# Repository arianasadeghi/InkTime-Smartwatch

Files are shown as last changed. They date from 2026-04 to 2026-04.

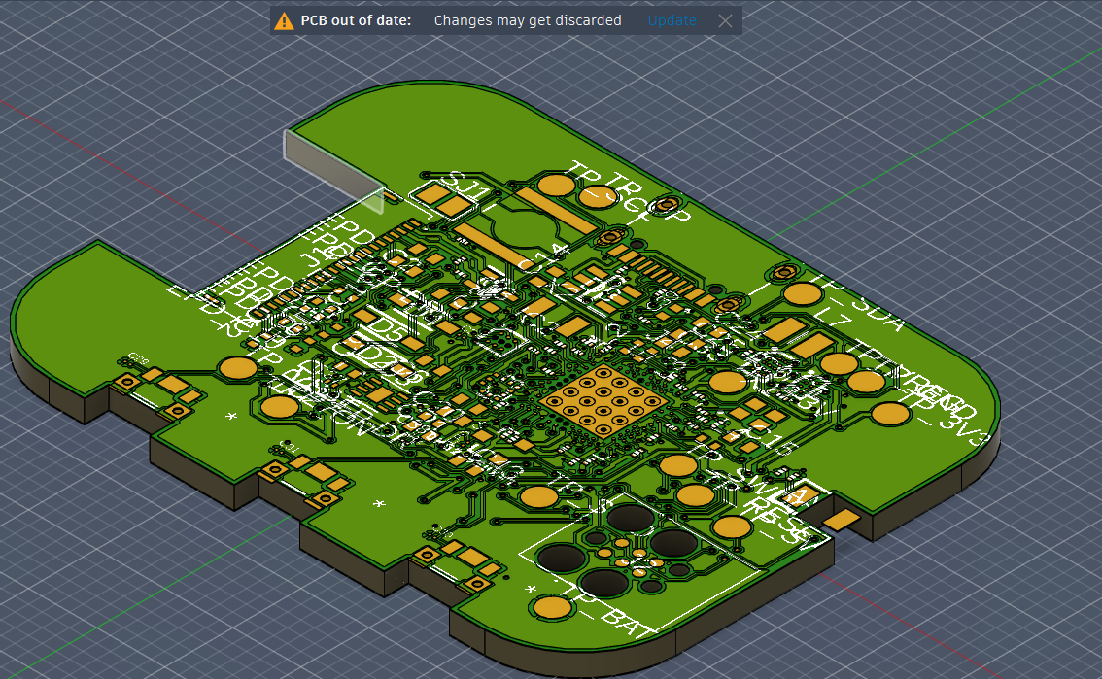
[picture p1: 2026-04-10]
IMAGES/3D1.png

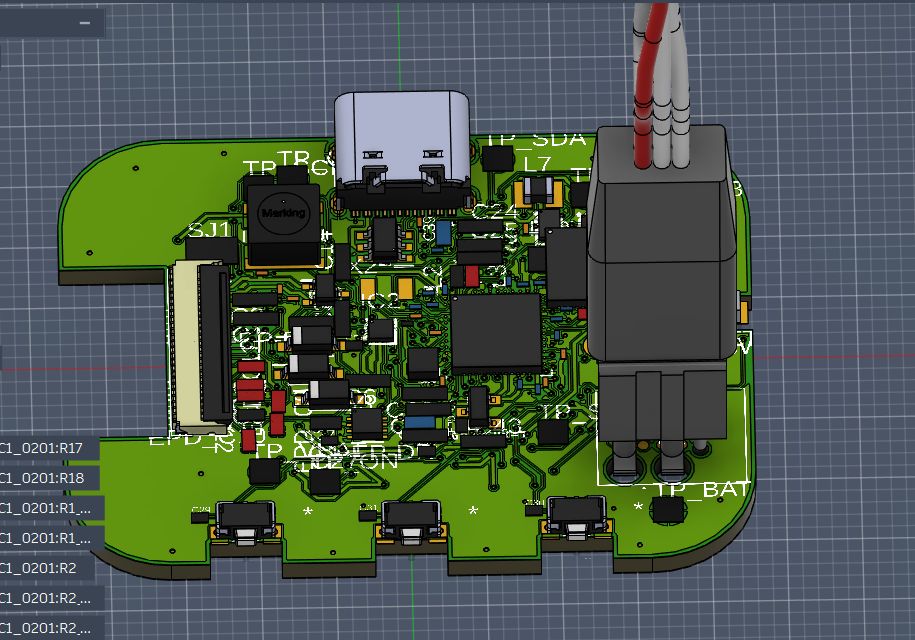
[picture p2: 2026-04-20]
IMAGES/PCB3D.png

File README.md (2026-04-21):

# InkTime - Open Source Smartwatch

InkTime este un proiect de smartwatch accesibil, open-source, conceput cu un accent puternic pe eficiența energetică și autonomia bateriei. Dispozitivul este construit în jurul ecosistemului nRF52840 (oferind conectivitate Bluetooth Low Energy) și folosește un ecran E-Ink pentru a asigura o vizibilitate excelentă în lumina soarelui cu un consum de energie aproape nul în stand-by.

Acest repository conține fișierele de design hardware pentru faza **EVT (Engineering Validation Test)**.

## 1. Diagrama Bloc a Sistemului

```mermaid
graph TD
    %% Power Management
    USB[Mufă USB-C / Pogo Pins] -->|5V| CHG[IC Încărcare BQ24040]
    CHG --> BATT[Acumulator LiPo 3.7V]
    BATT --> LDO[Regulator LDO 3.3V Ultra-Low Iq]
    
    %% Core
    LDO -.->|3.3V| MCU[SoC nRF52840]
    
    %% Interfaces & Peripherals
    MCU <-->|SPI| EINK[Display E-Ink 1.54]
    MCU <-->|I2C| IMU[Accelerometru BMA400]
    MCU <-->|I2C| HR[Senzor Puls MAX30102]
    MCU -->|GPIO| VIB[Motor Vibrații]
    MCU -->|GPIO| BTN[Butoane Navigare]
    
    %% Power lines
    LDO -.->|3.3V| EINK
    LDO -.->|3.3V| IMU
    LDO -.->|3.3V| HR
```

## 2. Bill Of Materials (BOM)

Tabelul de mai jos conține componentele principale folosite în designul plăcii. Lista completă (inclusiv rezistențe și condensatoare) se găsește în fișierul .csv din folderul Manufacturing.
| Componenta | Rol în sistem | JLC Part # | Link Datasheet |
| :--- | :--- | :--- | :--- |
| **nRF52840-QIAA** | Microcontroller principal (BLE, Cortex-M4F) | C206001 | [Datasheet nRF52840](https://infocenter.nordicsemi.com/pdf/nRF52840_PS_v1.7.pdf) |
    | **BQ24040DSQR** | IC Incarcare Acumulator LiPo (1A) | C43012 | [Datasheet BQ24040](https://www.ti.com/lit/ds/symlink/bq24040.pdf) |
| **TPS7A0533PDQNR** | LDO 3.3V (Consum Quiescent extrem de mic - 1µA) | C396492 | [Datasheet TPS7A05](https://www.ti.com/lit/ds/symlink/tps7a05.pdf) |
| **BMA400** | Accelerometru Ultra-Low Power (Pedometer) | C383215 | [Datasheet BMA400](https://www.bosch-sensortec.com/media/boschsensortec/downloads/datasheets/bst-bma400-ds000.pdf) |
| **MAX30102** | Senzor Optic Puls și SpO2 | C84666 | [Datasheet MAX30102](https://www.analog.com/media/en/technical-documentation/data-sheets/MAX30102.pdf) |
| **Ecran E-Ink 1.54 inch** | Display principal (SPI) | N/A (Modul) | [Datasheet Waveshare](https://www.waveshare.com/wiki/1.54inch_e-Paper_Module) |
## 3. Descrierea Functionalitatii Hardware

### Procesare si Conectivitate:
Inima ceasului InkTime este SoC-ul Nordic nRF52840. A fost ales datorita suportului nativ pentru Bluetooth 5.0 (BLE), esential pentru sincronizarea notificarilor cu telefonul mobil. Arhitectura ARM Cortex-M4F permite procesarea eficienta a algoritmilor de numarare a pasilor si calcul al ritmului cardiac.

### Managementul Consumului de Energie (Power Tree):
Fiind un dispozitiv wearable, constrângerile de baterie sunt critice.

Sistemul este alimentat de o baterie LiPo de mici dimensiuni (ex. 200mAh).

Încărcarea se face la 5V printr-un circuit BQ24040, reglat din rezistențe pentru a oferi un curent de încărcare mic și sigur (ex. 100mA).

Pentru a coborî tensiunea la 3.3V am folosit un LDO din seria TPS7A05, care are un curent de repaus (Iq) de doar 1µA, esențial pentru a nu drena bateria când ceasul este în Deep Sleep.

### Periferice și Interfețe:

Display-ul E-Ink: Comunică prin protocol SPI. Deși are un framerate mic, este perfect pentru un ceas deoarece consumă 0mA pentru a menține imaginea afișată.

Senzorii (IMU & HR): Comunicația se realizează pe o magistrală I2C partajată. BMA400 are un mod special de "step counter" hardware care poate trezi microcontroller-ul din sleep doar când utilizatorul face un pas, economisind masiv energia.

## 4. Alocarea Pinilor nRF52840

Microcontroller-ul nRF52840 permite maparea flexibilă a pinilor (orice funcție digitală pe orice pin), lucru care a facilitat o rutare curată (fără suprapuneri) pe PCB.
| Pin nRF52840 | Nume Net / Funcție | Justificare / Detalii |
| :--- | :--- | :--- |
| **P0.13 / P0.14 / P0.15** | `SPI_SCK`, `SPI_MOSI`, `SPI_MISO` | Magistrala SPI dedicată ecranului E-Ink. Pinii au fost aleși pe aceeași latură a chip-ului cu conectorul FPC al ecranului. |
| **P0.16** | `EINK_CS` (Chip Select) | Activare magistrală SPI pentru ecran. |
| **P0.17 / P0.18** | `EINK_DC`, `EINK_RST` | Pini de control adiționali (Data/Command și Reset) necesari controller-ului de E-Ink. |
| **P0.26 / P0.27** | `I2C_SDA`, `I2C_SCL` | Magistrala I2C pentru accelerometru (BMA400) și senzorul de puls (MAX30102). Conține rezistențe de pull-up de 4.7k. |
| **P1.02** | `IMU_INT` (Interrupt) | Pin setat ca Input. BMA400 trimite un semnal aici pentru a trezi SoC-ul când detectează mișcare. |
| **P1.06** | `MOTOR_PWM` | Pin configurat ca ieșire PWM, conectat la poarta unui tranzistor MOSFET N-Channel pentru a acționa motorul de vibrații (notificări haptice). |
| **P0.11 / P0.12** | `BTN_UP`, `BTN_DOWN` | Pini conectați la butoanele laterale, configurați cu Input Pull-Up intern. |
## 5. Design Log & Integrare Mecanică (EVT Phase)

### Construcția PCB-ului: 
Cablajul a fost realizat pe 2 straturi. Pentru a asigura performanța antenei, a fost respectată zona de keepout cerută în datasheet-ul antenei ceramice (sau PCB trace), neavând planuri de masă sub aceasta.

### Constrângeri Mecanice: 
Forma PCB-ului a fost dictată strict de fișierul .step al carcasei primite. Decupajele plăcii se aliniază perfect cu pinii de montare ai carcasei.

### Stack-up 3D: 
Modelul 3D final validează faptul că placa de bază, bateria (poziționată sub PCB) și display-ul E-Ink (deasupra PCB-ului) intră în carcasa de smartwatch fără coliziuni de componente.

## 5. Calcule Detaliate de Consum de Energie (Power Budget)

Pentru a estima durata de viata a bateriei, am analizat consumul principalelor componente din circuit (nRF52840, IMU, DC/DC converter) in doua scenarii principale: Mod Activ si Mod Sleep (Standby).

### 1. Parametrii Bateriei
* Tip baterie: Li-Po
* Tensiune nominala: 3.7V
* Capacitate: 500 mAh

### 2. Consum in Mod Activ (Transmisie BLE + Achizitie Date IMU)
Cand dispozitivul este treaz, citeste date de la senzori si transmite pachete prin Bluetooth.
* nRF52840 (CPU + TX/RX la 0dBm): ~14.0 mA
* Senzor IMU (Mod Activ): ~1.0 mA
* Pierderi DC/DC Converter (Eficienta 90%): ~1.5 mA
* Total Consum Activ: ~16.5 mA

### 3. Consum in Mod Sleep (Standby / System OFF)
Cand dispozitivul nu este folosit, microcontrolerul intra in deep sleep, iar senzorii sunt trecuti in power-down.
* nRF52840 (System OFF, RAM retention): ~1.5 uA (0.0015 mA)
* Senzor IMU (Mod Power-Down): ~5.0 uA (0.005 mA)
* Quiescent Current DC/DC + LDO: ~10.0 uA (0.01 mA)
* Total Consum Sleep: ~16.5 uA (0.0165 mA)

### 4. Estimarea Duratei de Viata a Bateriei (Battery Life)

Scenariul A: Utilizare Continua (100% Mod Activ)
Daca dispozitivul ar transmite date non-stop:
* 500 mAh / 16.5 mA = 30.3 ore de functionare continua.

Scenariul B: Dispozitiv lasat pe birou (100% Mod Sleep)
Daca dispozitivul este pur si simplu lasat in stand-by:
* 500 mAh / 0.0165 mA = 30,303 ore = Aproximativ 3.4 ani.

Scenariul C: Utilizare Realista (Mix: 5% Activ, 95% Sleep)
Presupunand ca dispozitivul se trezeste periodic pentru a trimite date:
* Consum mediu = (16.5 mA * 0.05) + (0.0165 mA * 0.95) = 0.825 mA + 0.015 mA = 0.84 mA

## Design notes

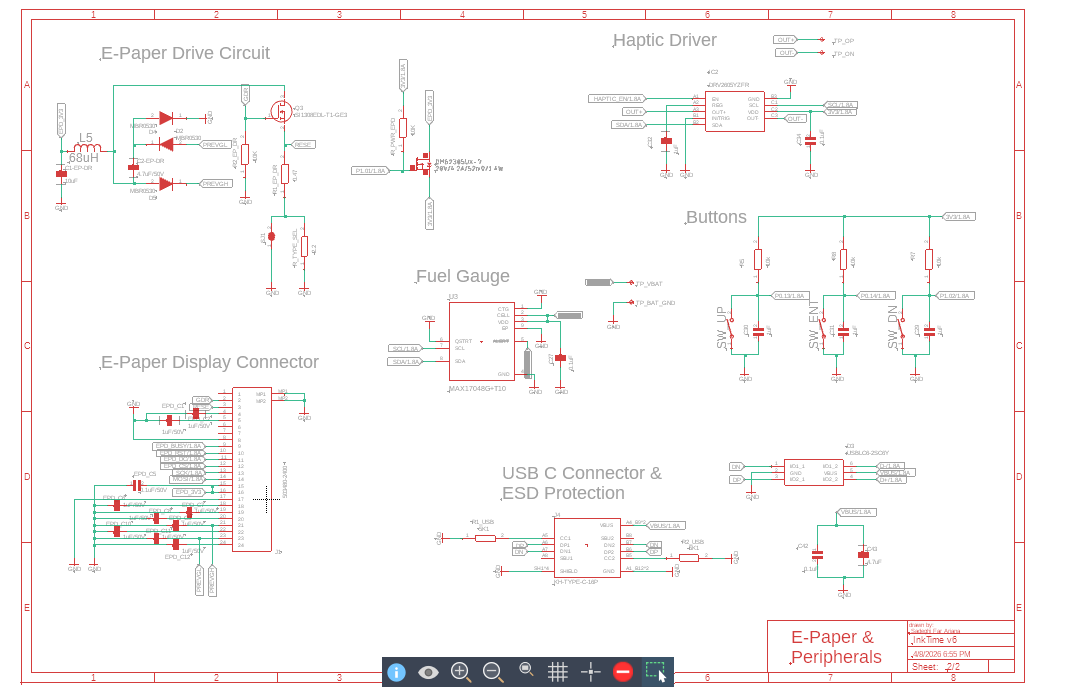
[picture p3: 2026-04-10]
IMAGES/Schematic2.png

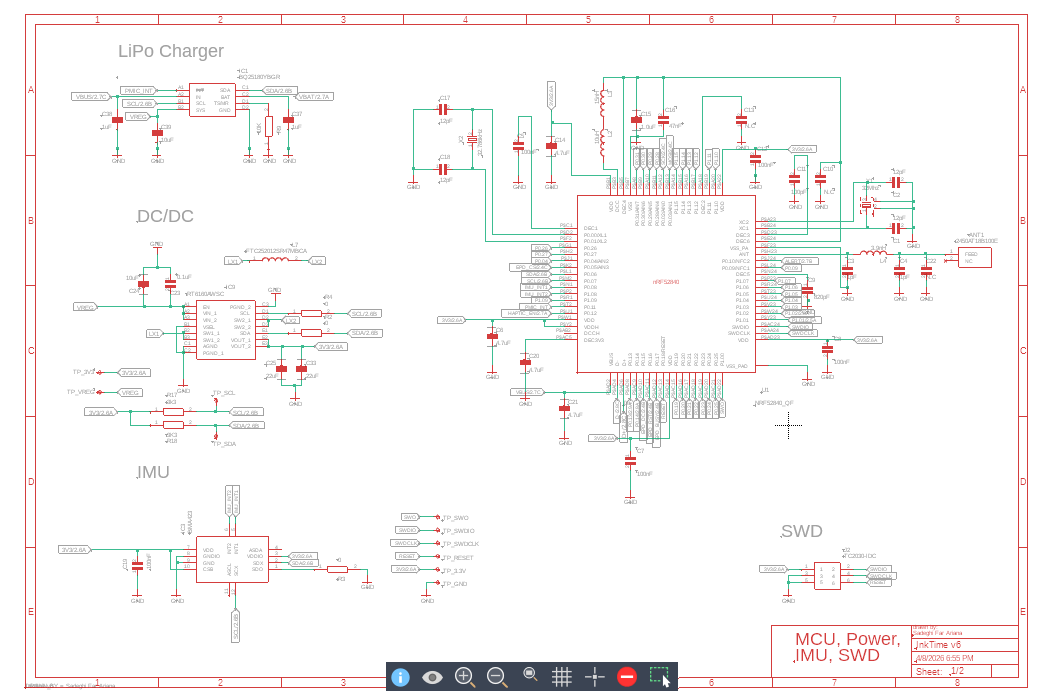
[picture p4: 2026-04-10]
IMAGES/Schematic1.png

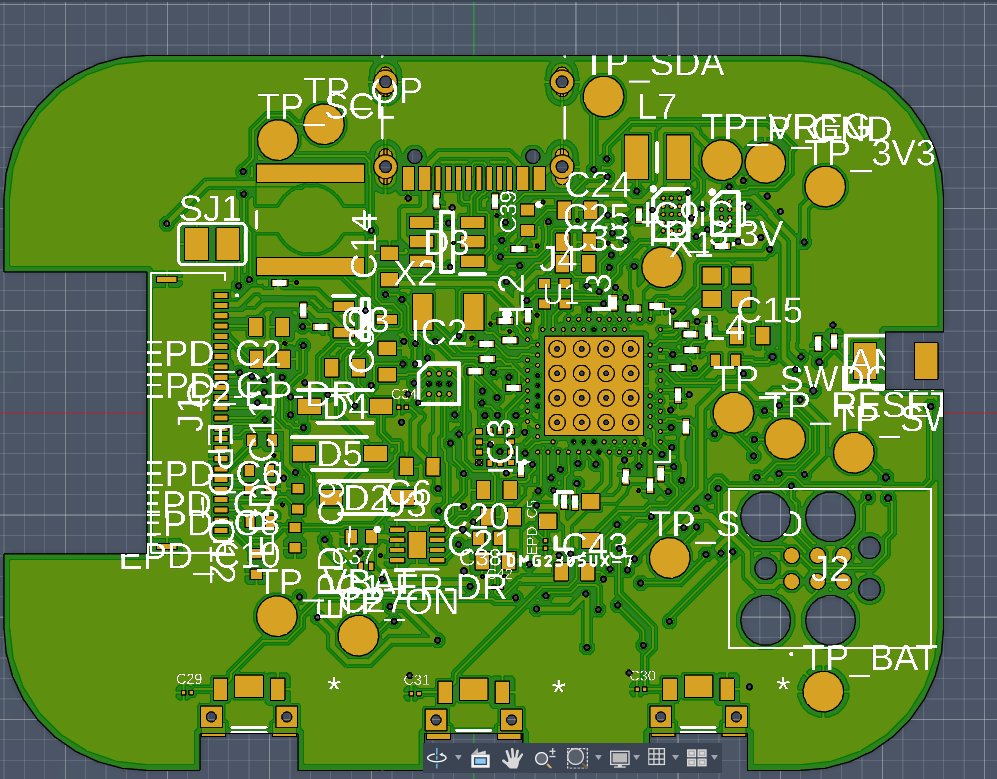
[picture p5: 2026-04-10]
IMAGES/3D2.png

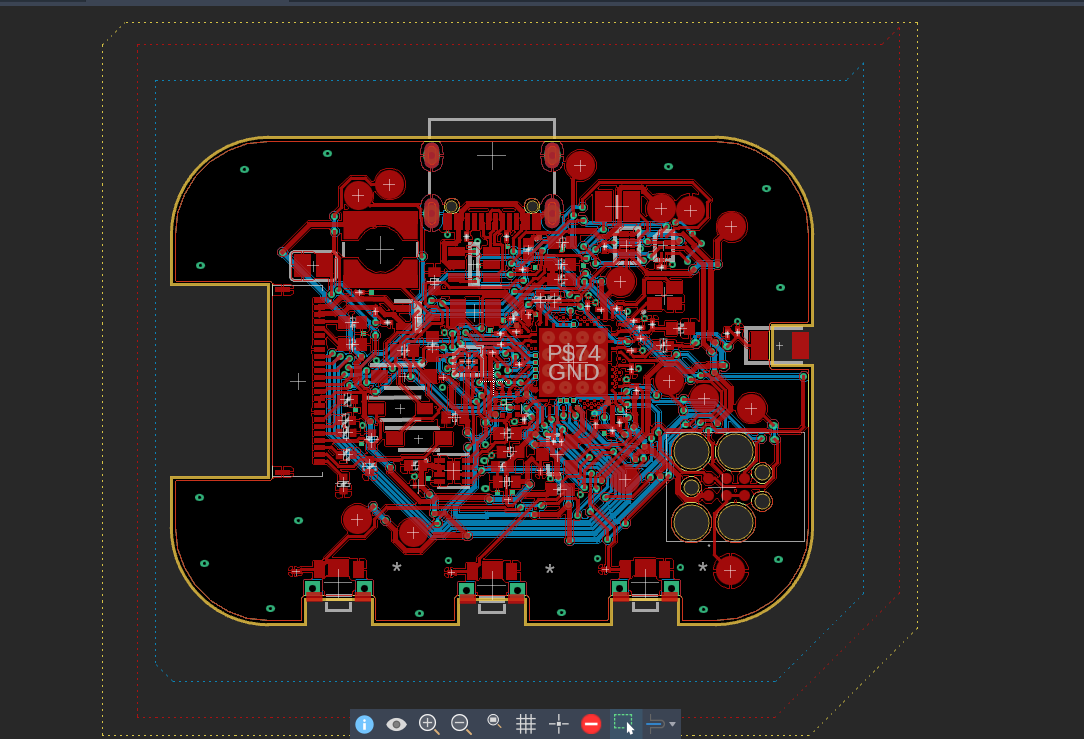
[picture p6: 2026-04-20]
IMAGES/PCB.png

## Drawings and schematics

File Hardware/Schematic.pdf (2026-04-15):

# LiPo Charger

1 2 C18

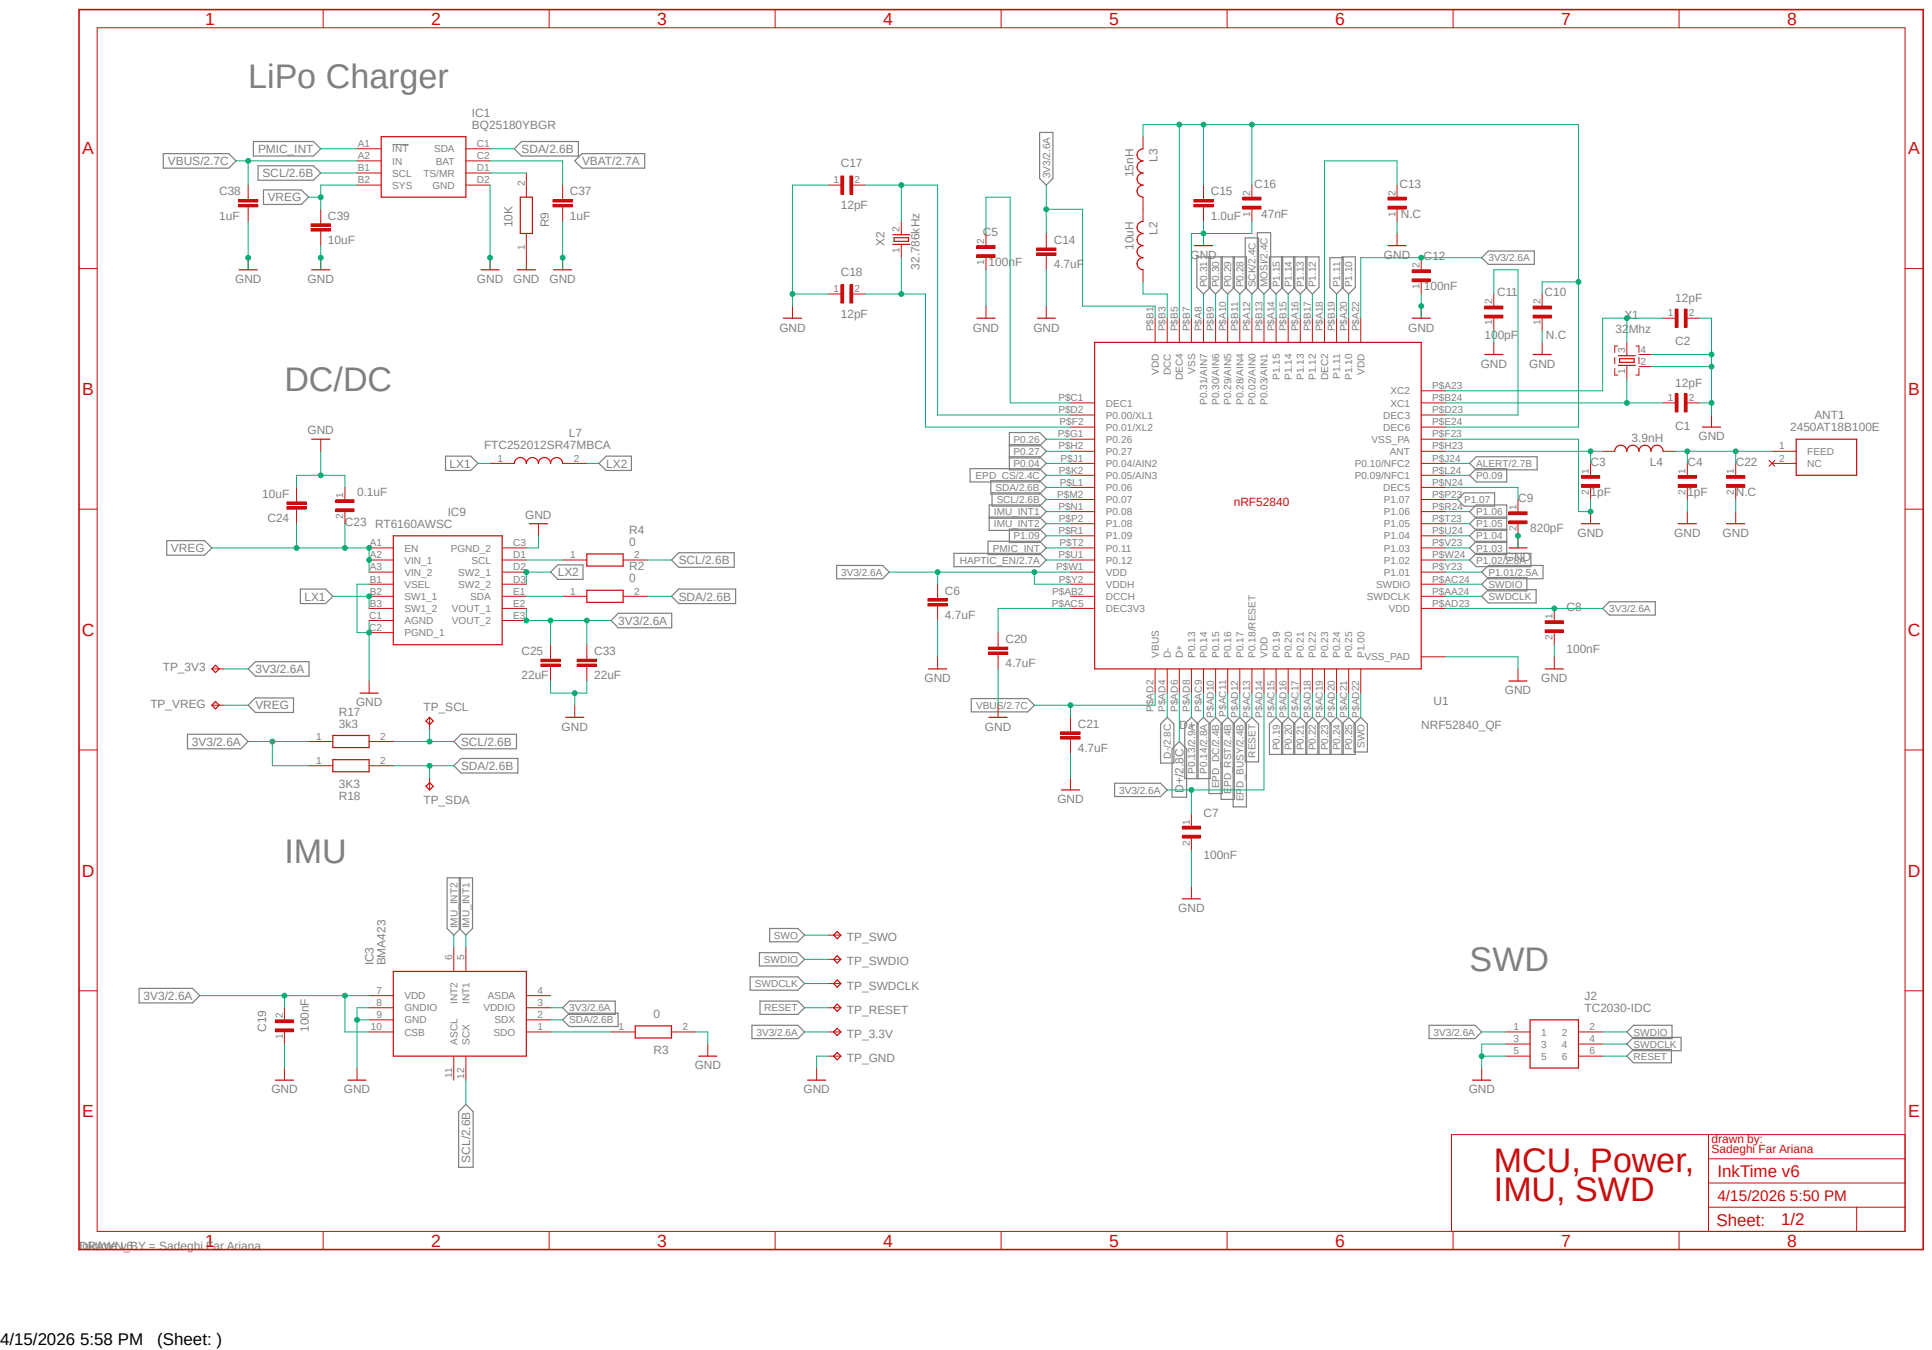
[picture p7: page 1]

6 VDD 7 GNDIO 8 GND 9 CSB 10 ASCL 11 SCX 12

IMU, SWD | drawn by: Sadeghi Far Ariana MCU, Power,

Sheet: 1/2

DRAWN_BY = Sadeghi Far Ariana Inktime v6

# Haptic Driver E-Paper Drive Circuit

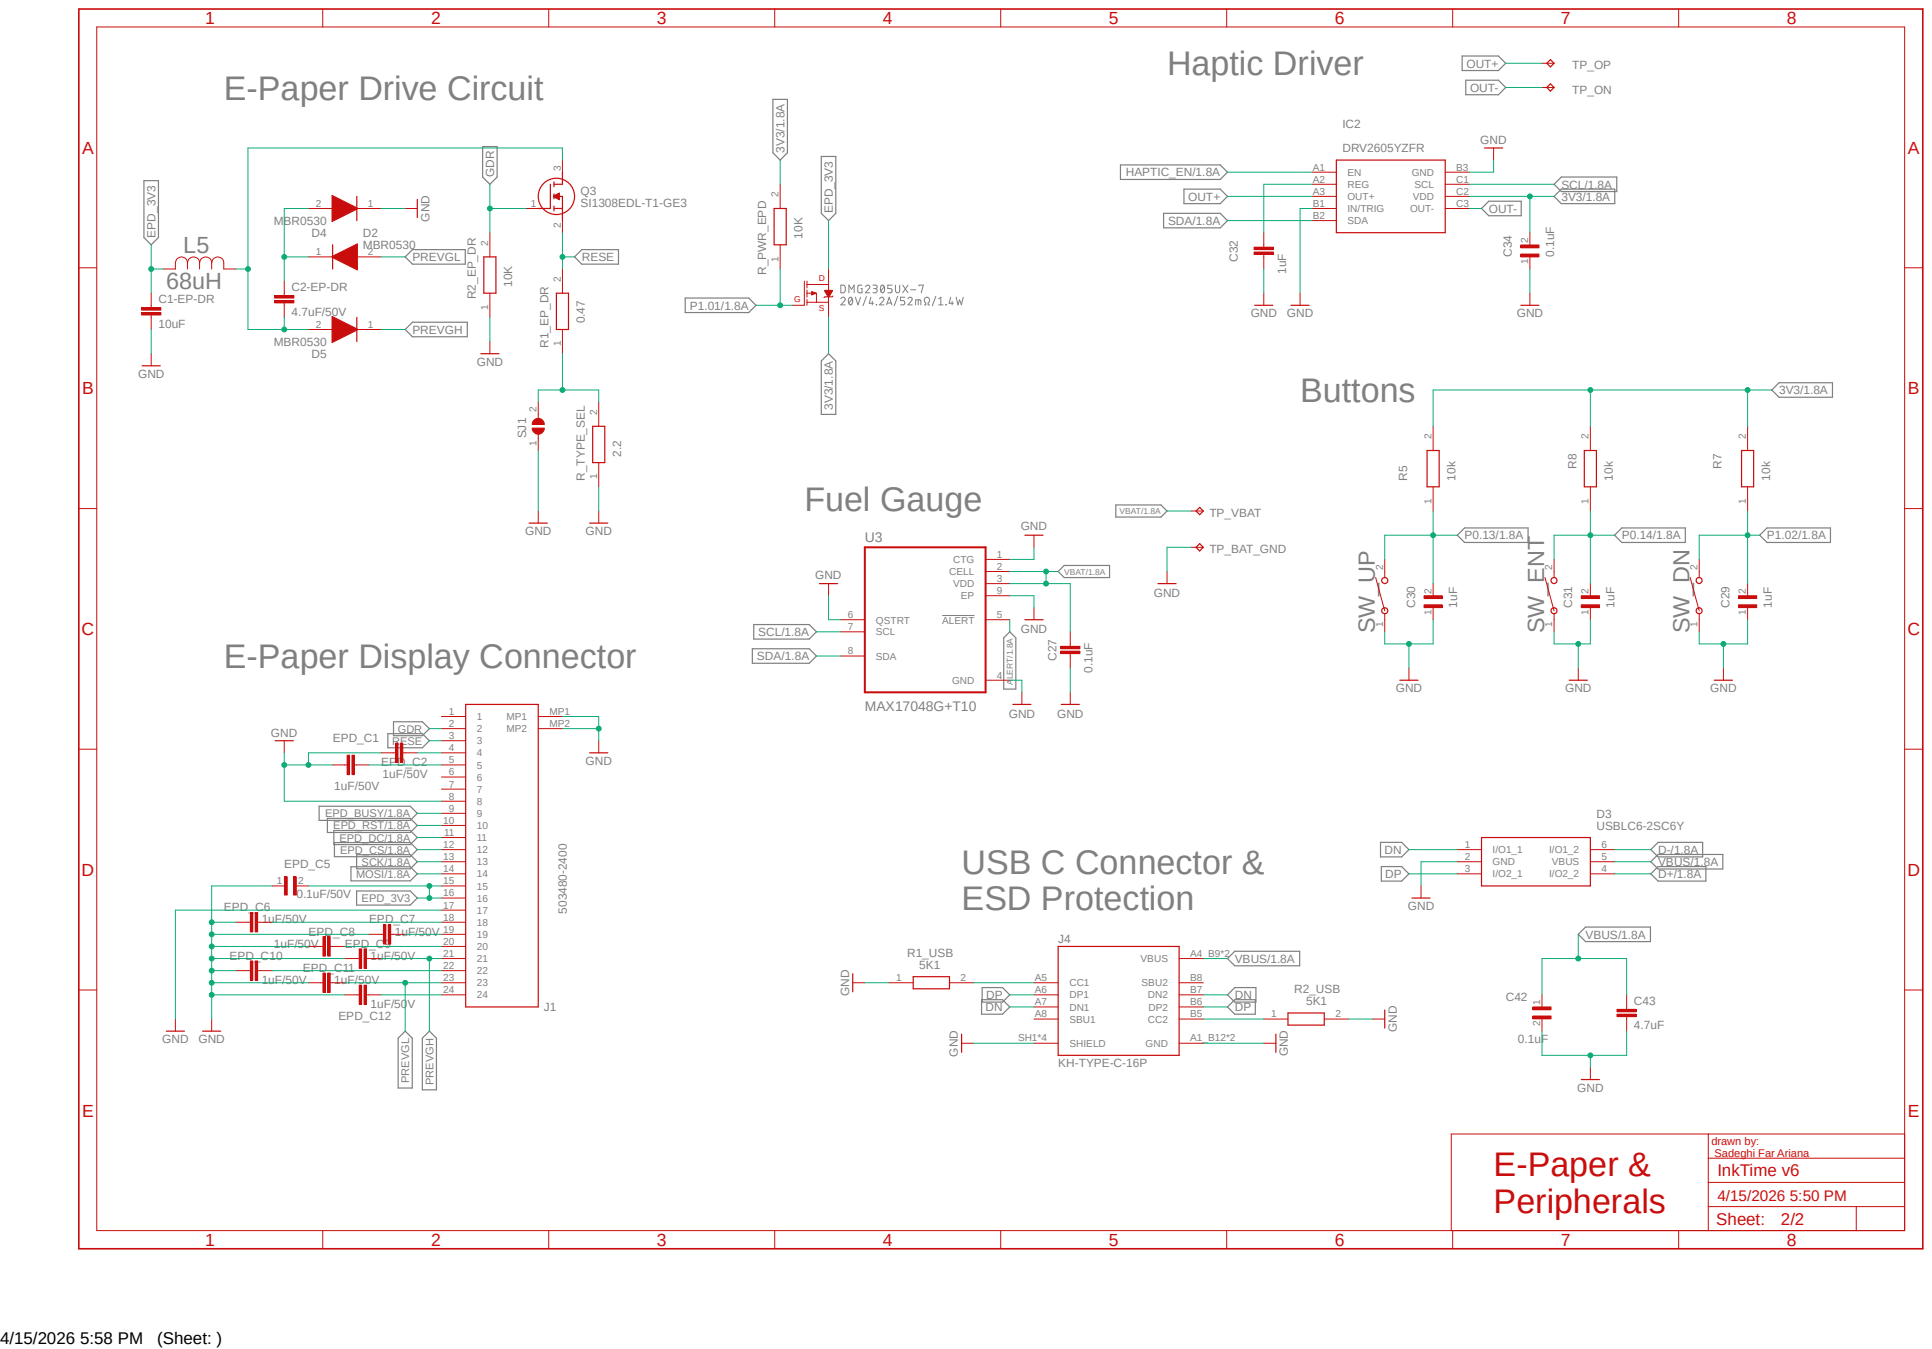
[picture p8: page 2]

1uF/50V EPD_C7 | 18 18
1uF/50V | EPD_C9 | | 20 20

EPD_C8 | 1uF/50V | 19 19

EPD_C10 | | 1uF/50V | 21 21
1uF/50V | 1uF/50V | | 23 23

EPD_C11 | | | 22 22

Sadeghi Far Ariana E-Paper &
Peripherals

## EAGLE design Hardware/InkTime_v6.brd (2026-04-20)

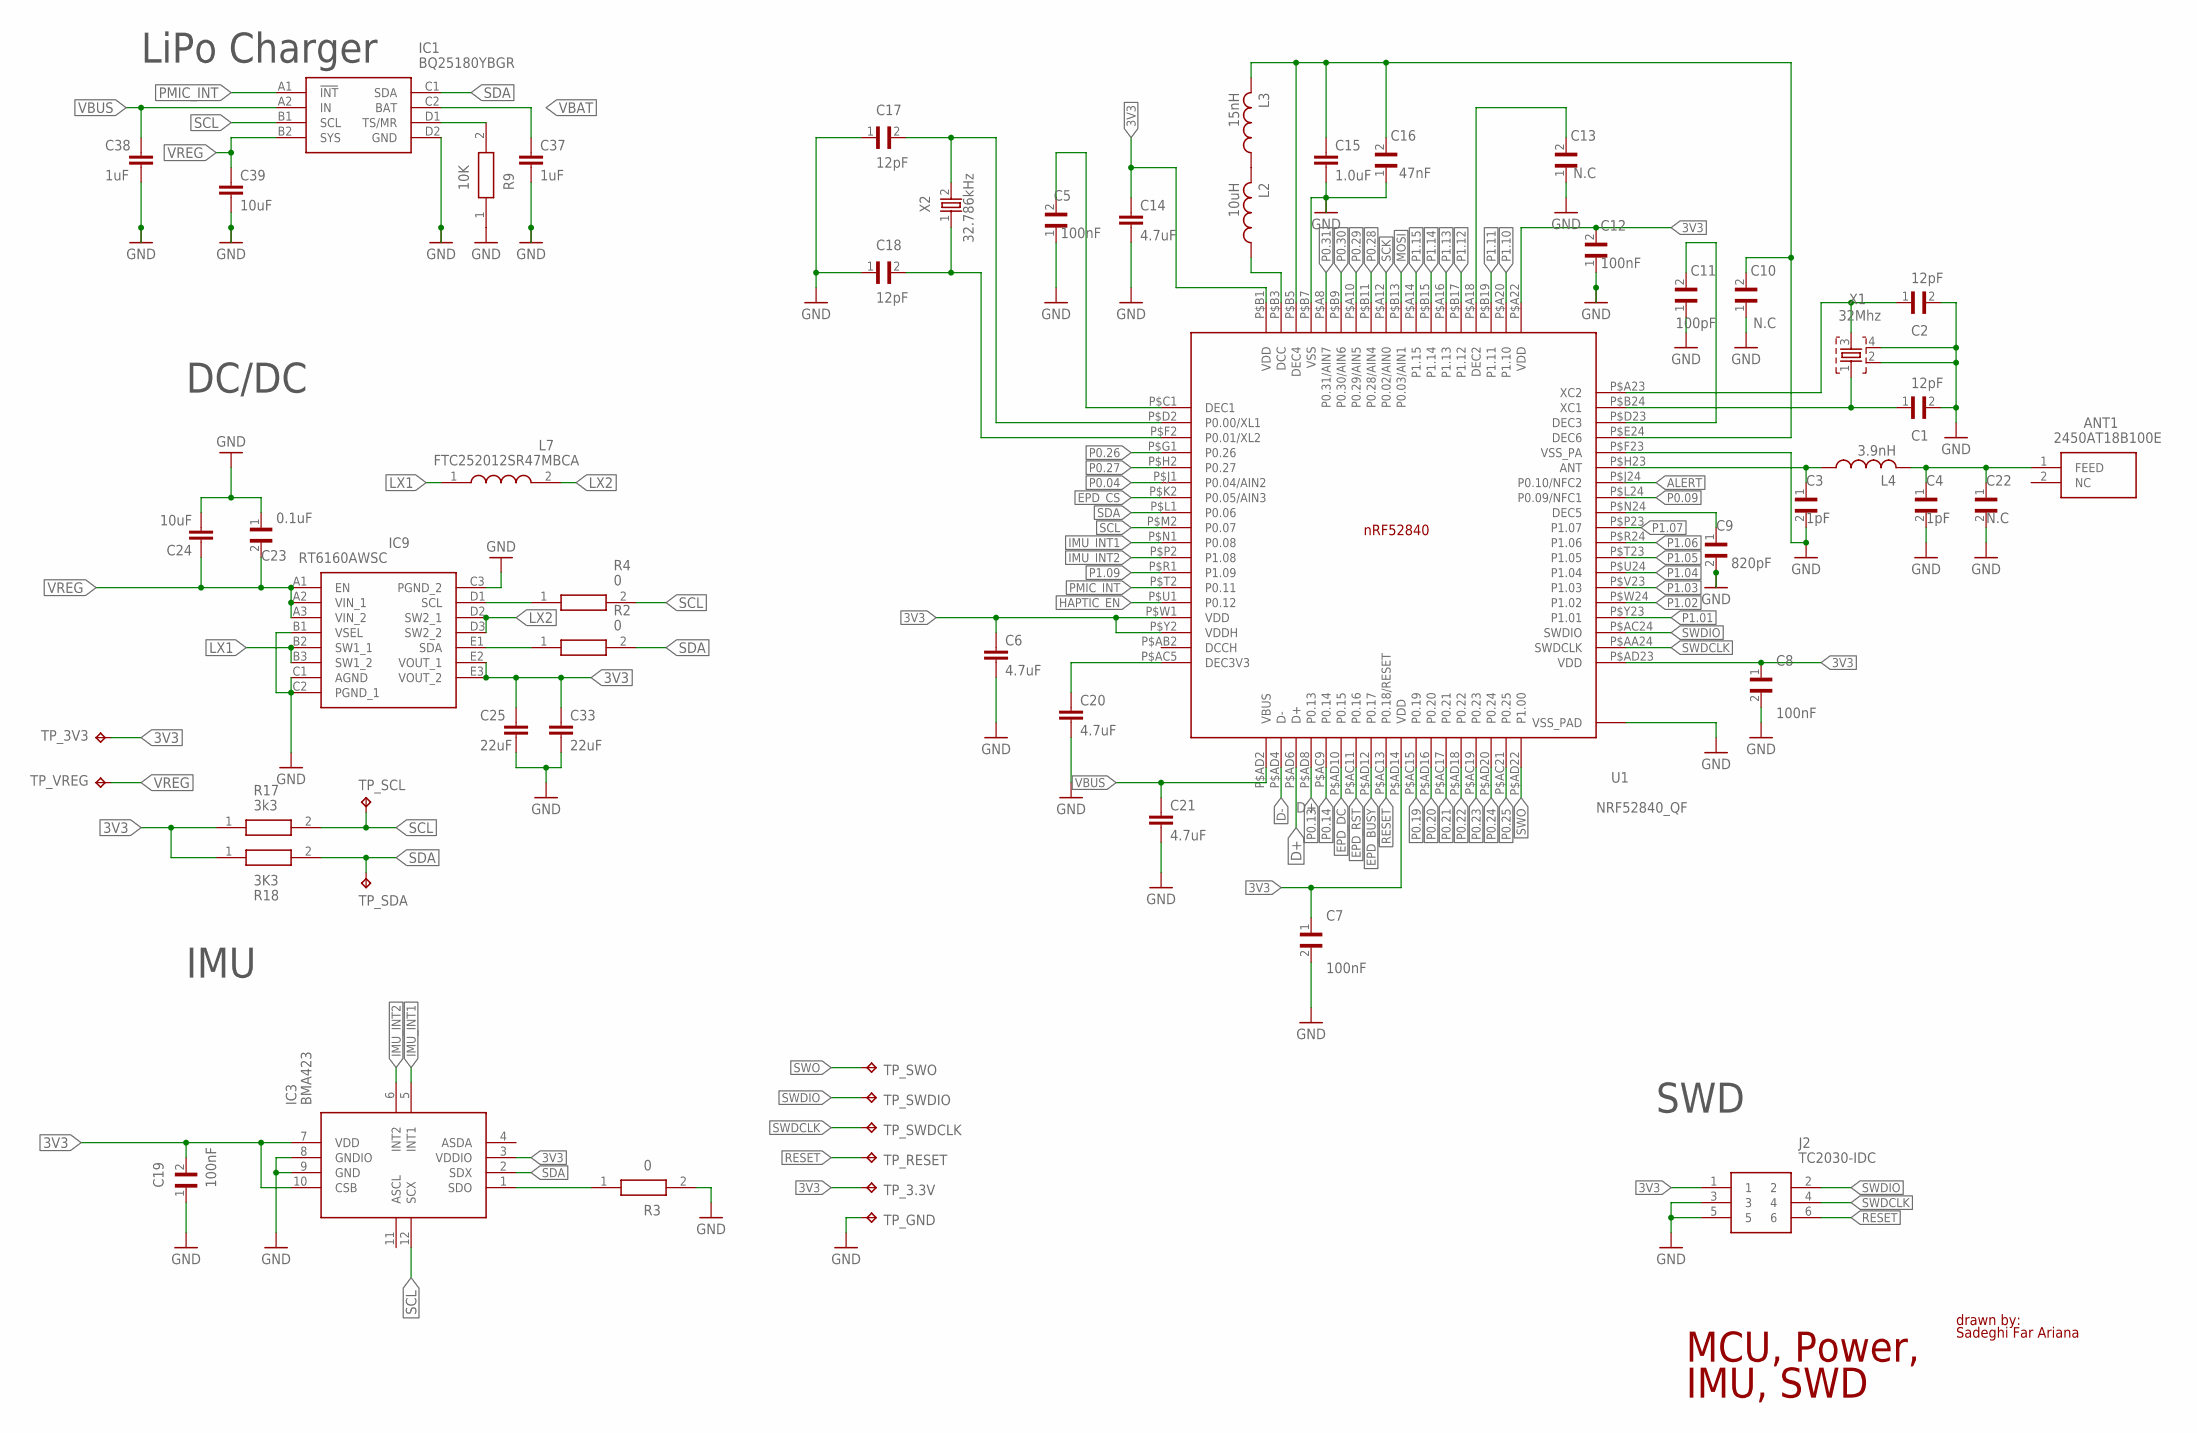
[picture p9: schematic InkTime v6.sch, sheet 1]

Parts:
ANT1: 2450AT18B100E; 2450AT18B100E_ANTC3216X140N
C1, C2, C17, C18: 12pF; GRM011R60J152KE01L_1_0201
C3, C4: 1pF; GRM011R60J152KE01L_1_0201
C5, C7, C8, C12, C19: 100nF; GRM011R60J152KE01L_1_0201
C6, C14, C20, C21: 4.7uF; ESP32_C6_LIBRARY_1_ESP32_WROVER_EAGLE-LTSPICE_C0402
C9: 820pF; GRM011R60J152KE01L_1_0201
C10, C13, C22: N.C; GRM011R60J152KE01L_1_0201
C11: 100pF; GRM011R60J152KE01L_1_0201
C15: 1.0uF; ESP32_C6_LIBRARY_1_ESP32_WROVER_EAGLE-LTSPICE_C0402
C16: 47nF; GRM011R60J152KE01L_1_0201
C23: 0.1uF; GRM011R60J152KE01L_1_0201
C24: 10uF; ESP32_C6_LIBRARY_1_ESP32_WROVER_EAGLE-LTSPICE_C0402
C25, C33: 22uF; ESP32_C6_LIBRARY_1_ESP32_WROVER_EAGLE-LTSPICE_C0402
C37, C38: 1uF; PERFECT_0402_0402
C39: 10uF; PERFECT_0402_0402
IC1: BQ25180YBGR; BQ25180YBGR_BGA8C40P2X4_100X155X50
IC3: BMA423; BMA423_BMA423
IC9: RT6160AWSC; RT6160AWSC_BGA15C40P3X5_140X230X60
J2: TC2030-IDC; TC2030-IDC_TC2030IDC
L2: 10uH; NORDIC_NRF_2_RESC0402_L
L3: 15nH; NORDIC_NRF_2_RESC0402_L
L4: 3.9nH; NORDIC_NRF_2_RESC0402_L
L7: FTC252012SR47MBCA; MLP2016SR47MT0S1_INDC2016X100N
R2, R3, R4: 0; CPF0201D7K68C1_0201
R9: 10K; ERA-1AEB3401C_0201
R17: 3k3; CPF0201D7K68C1_0201
R18: 3K3; CPF0201D7K68C1_0201
TP_3.3V, TP_3V3: HECTOR_WATCH_1_TPTP20R; HECTOR_WATCH_1_TP20R
TP_GND: HECTOR_WATCH_1_TPTP20R; HECTOR_WATCH_1_TP20R
TP_RESET: HECTOR_WATCH_1_TPTP20R; HECTOR_WATCH_1_TP20R
TP_SCL: HECTOR_WATCH_1_TPTP20R; HECTOR_WATCH_1_TP20R
TP_SDA: HECTOR_WATCH_1_TPTP20R; HECTOR_WATCH_1_TP20R
TP_SWDCLK: HECTOR_WATCH_1_TPTP20R; HECTOR_WATCH_1_TP20R
TP_SWDIO: HECTOR_WATCH_1_TPTP20R; HECTOR_WATCH_1_TP20R
TP_SWO: HECTOR_WATCH_1_TPTP20R; HECTOR_WATCH_1_TP20R
TP_VREG: HECTOR_WATCH_1_TPTP20R; HECTOR_WATCH_1_TP20R
U1: NRF52840_QF; NORDIC_NRF_4_AQFN50P700X700X85_HS-74N
X1: 32Mhz; NORDIC_NRF_BT-XTAL_2016_N
X2: 32.786kHz; NORDIC_NRF_1_XTAL_3215_N

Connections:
3V3: C6.1, C7.1, C8.1, C12.2, C14.1, C19.2, C25.1, C33.1, IC3.3 (VDDIO), IC3.7 (VDD), IC3.10 (CSB), IC9.E2 (VOUT_1), IC9.E3 (VOUT_2), J2.1, R17.1, R18.1, TP_3.3V.TP, TP_3V3.TP, U1.P$A22 (VDD), U1.P$AD14 (VDD), U1.P$AD23 (VDD), U1.P$B1 (VDD), U1.P$W1 (VDD), U1.P$Y2 (VDDH); also elsewhere on the board
ALERT: U1.P$J24 (P0.10/NFC2); also elsewhere on the board
D+: U1.P$AD6 (D+); also elsewhere on the board
D-: U1.P$AD4 (D-); also elsewhere on the board
EPD_BUSY: U1.P$AD12 (P0.17); also elsewhere on the board
EPD_CS: U1.P$K2 (P0.05/AIN3); also elsewhere on the board
EPD_DC: U1.P$AD10 (P0.15); also elsewhere on the board
EPD_RST: U1.P$AC11 (P0.16); also elsewhere on the board
HAPTIC_EN: U1.P$U1 (P0.12); also elsewhere on the board
IMU_INT1: IC3.5 (INT1), U1.P$N1 (P0.08)
IMU_INT2: IC3.6 (INT2), U1.P$P2 (P1.08)
LX1: IC9.B2 (SW1_1), IC9.B3 (SW1_2), L7.1
LX2: IC9.D2 (SW2_1), IC9.D3 (SW2_2), L7.2
MOSI: U1.P$B13 (P0.03/AIN1); also elsewhere on the board
unnamed: L2.2, L3.1
unnamed: IC1.D1 (TS/MR), R9.2
unnamed: IC9.E1 (SDA), R2.1
unnamed: IC9.D1 (SCL), R4.1
unnamed: IC3.1 (SDO), R3.1
unnamed: C9.1, U1.P$N24 (DEC5)
unnamed: C3.1, L4.1, U1.P$H23 (ANT)
unnamed: ANT1.1 (FEED), C4.1, C22.1, L4.2
unnamed: C11.2, U1.P$D23 (DEC3)
unnamed: C1.1, U1.P$B24 (XC1), X1.1
unnamed: C2.1, U1.P$A23 (XC2), X1.3
unnamed: C10.2, C15.1, C16.2, L3.2, U1.P$B5 (DEC4), U1.P$E24 (DEC6)
unnamed: C13.2, U1.P$A18 (DEC2)
unnamed: L2.1, U1.P$B3 (DCC)
unnamed: C5.2, U1.P$C1 (DEC1)
unnamed: C17.2, U1.P$D2 (P0.00/XL1), X2.2
unnamed: C18.2, U1.P$F2 (P0.01/XL2), X2.1
unnamed: C20.1, U1.P$AC5 (DEC3V3)
P0.04: U1.P$J1 (P0.04/AIN2)
P0.09: U1.P$L24 (P0.09/NFC1)
P0.13: U1.P$AD8 (P0.13); also elsewhere on the board
P0.14: U1.P$AC9 (P0.14); also elsewhere on the board
P0.19: U1.P$AC15 (P0.19)
P0.20: U1.P$AD16 (P0.20)
P0.21: U1.P$AC17 (P0.21)
P0.22: U1.P$AD18 (P0.22)
P0.23: U1.P$AC19 (P0.23)
P0.24: U1.P$AD20 (P0.24)
P0.25: U1.P$AC21 (P0.25)
P0.26: U1.P$G1 (P0.26)
P0.27: U1.P$H2 (P0.27)
P0.28: U1.P$B11 (P0.28/AIN4)
P0.29: U1.P$A10 (P0.29/AIN5)
P0.30: U1.P$B9 (P0.30/AIN6)
P0.31: U1.P$A8 (P0.31/AIN7)
P1.01: U1.P$Y23 (P1.01); also elsewhere on the board
P1.02: U1.P$W24 (P1.02); also elsewhere on the board
P1.03: U1.P$V23 (P1.03)
P1.04: U1.P$U24 (P1.04)
P1.05: U1.P$T23 (P1.05)
P1.06: U1.P$R24 (P1.06)
P1.07: U1.P$P23 (P1.07)
P1.09: U1.P$R1 (P1.09)
P1.10: U1.P$A20 (P1.10)
P1.11: U1.P$B19 (P1.11)
P1.12: U1.P$B17 (P1.12)
P1.13: U1.P$A16 (P1.13)
P1.14: U1.P$B15 (P1.14)
P1.15: U1.P$A14 (P1.15)
PMIC_INT: IC1.A1 (!INT), U1.P$T2 (P0.11)
RESET: J2.6, TP_RESET.TP, U1.P$AC13 (P0.18/RESET)
SCK: U1.P$A12 (P0.02/AIN0); also elsewhere on the board
SCL: IC1.B1 (SCL), IC3.12 (SCX), R4.2, R17.2, TP_SCL.TP, U1.P$M2 (P0.07); also elsewhere on the board
SDA: IC1.C1 (SDA), IC3.2 (SDX), R2.2, R18.2, TP_SDA.TP, U1.P$L1 (P0.06); also elsewhere on the board
SWDCLK: J2.4, TP_SWDCLK.TP, U1.P$AA24 (SWDCLK)
SWDIO: J2.2, TP_SWDIO.TP, U1.P$AC24 (SWDIO)
SWO: TP_SWO.TP, U1.P$AD22 (P1.00)
VBAT: C37.1, IC1.C2 (BAT); also elsewhere on the board
VBUS: C21.1, C38.1, IC1.A2 (IN), U1.P$AD2 (VBUS); also elsewhere on the board
VREG: C23.2, C24.1, C39.1, IC1.B2 (SYS), IC9.A1 (EN), IC9.A2 (VIN_1), IC9.A3 (VIN_2), TP_VREG.TP

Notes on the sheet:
drawn by: Sadeghi Far Ariana
MCU, Power, IMU, SWD
LiPo Charger
DC/DC
IMU
SWD

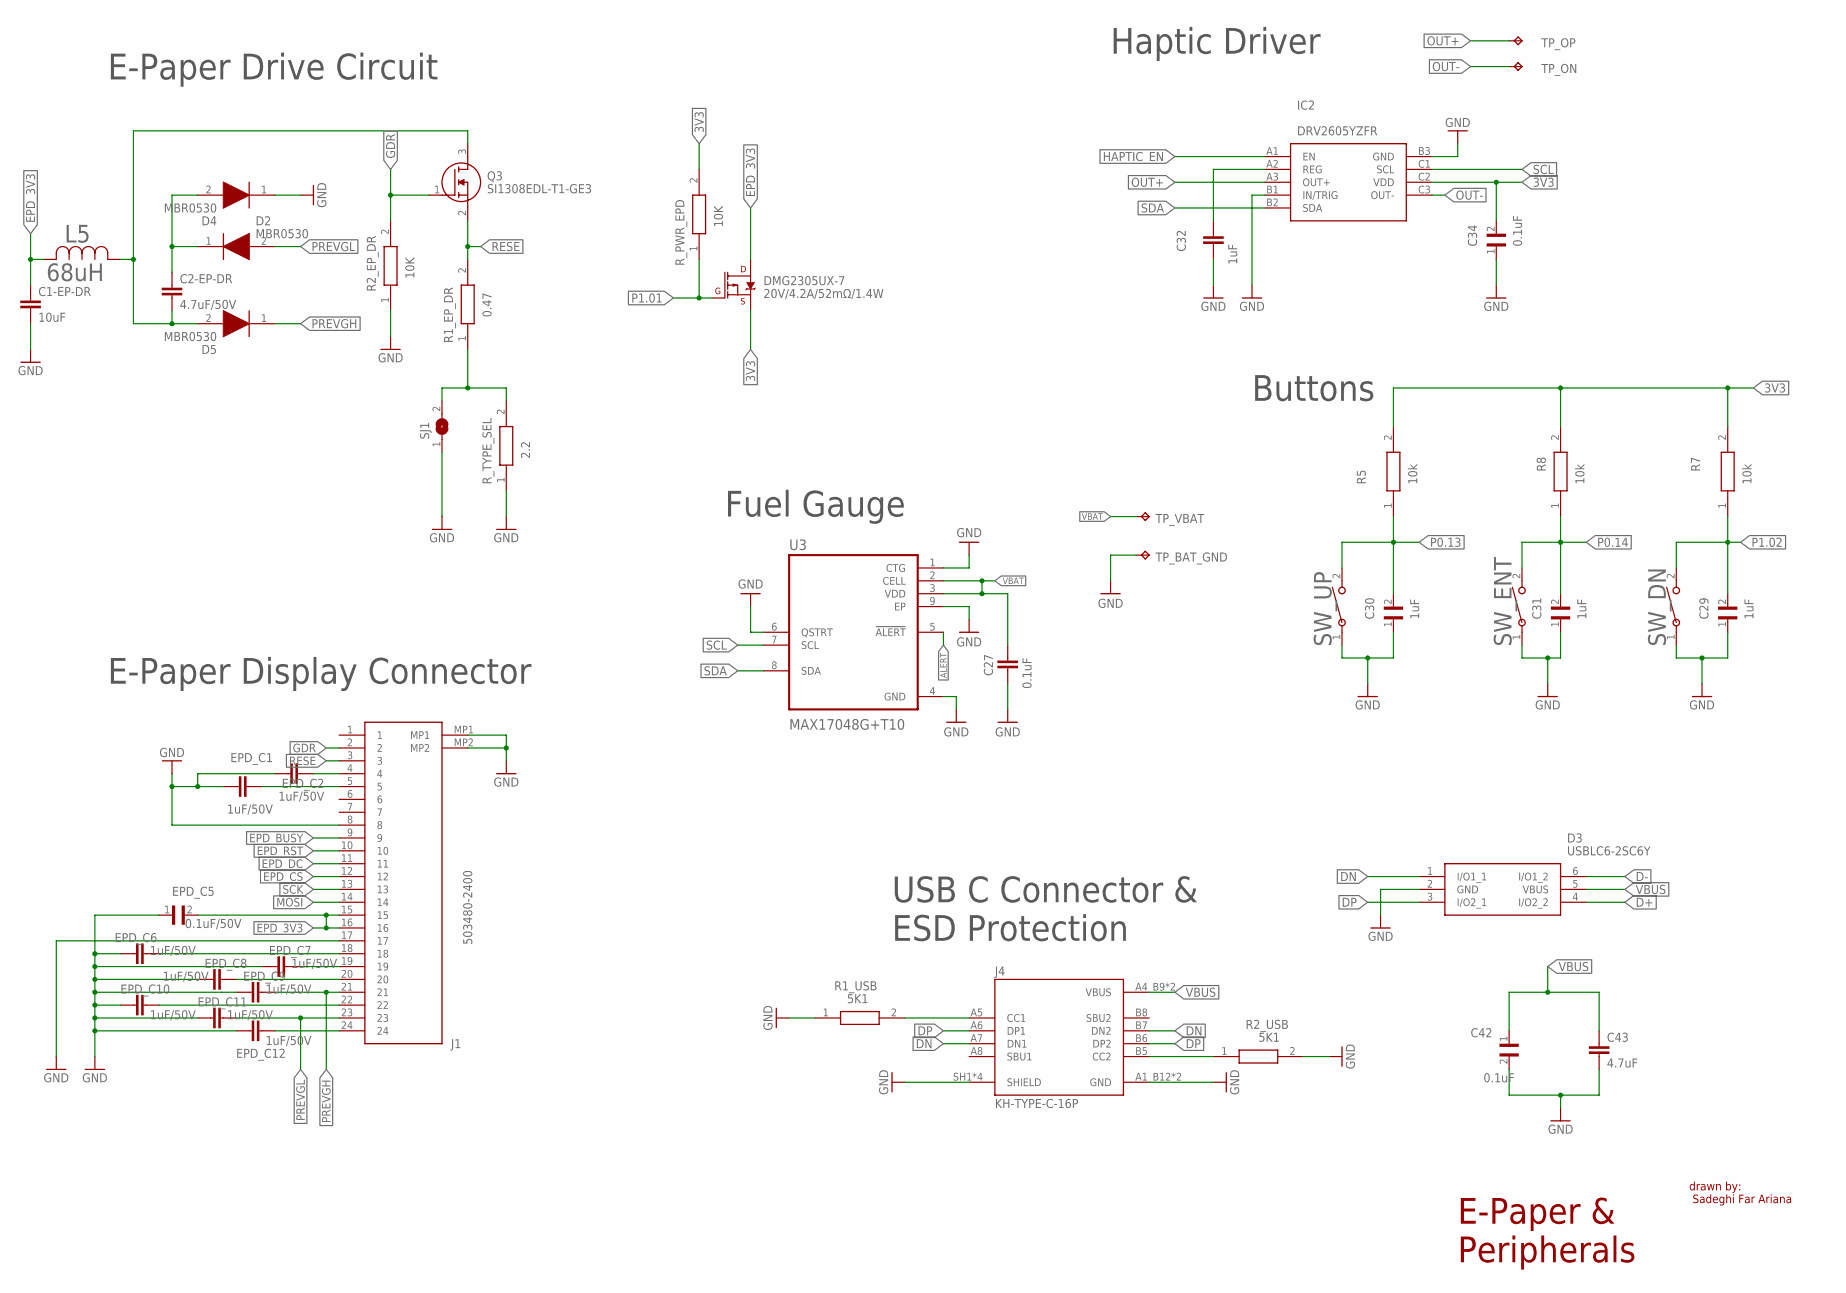
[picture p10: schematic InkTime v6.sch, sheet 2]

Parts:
C1-EP-DR: 10uF; ESP32_C6_LIBRARY_1_ESP32_WROVER_EAGLE-LTSPICE_C0402
C2-EP-DR: 4.7uF/50V; ESP32_C6_LIBRARY_1_ESP32_WROVER_EAGLE-LTSPICE_C0402
C27: 0.1uF; NORDIC_NRF_3_RESC0201_L
C29, C30, C31: 1uF; GRM011R60J152KE01L_2_CAPC0201X13N
C32: 1uF; ESP32_C6_LIBRARY_1_ESP32_WROVER_EAGLE-LTSPICE_C0402
C34, C42: 0.1uF; GRM011R60J152KE01L_2_CAPC0201X13N
C43: 4.7uF; ESP32_C6_LIBRARY_1_ESP32_WROVER_EAGLE-LTSPICE_C0402
D2, D4, D5: MBR0530; ESP32_C6_LIBRARY_5_SOD3716X135N
D3: USBLC6-2SC6Y; ESP32_C6_LIBRARY_3_SOT95P280X145-6N
DMG2305UX-7: 20V/4.2A/52mΩ/1.4W; ESP32_C6_LIBRARY_4_ESP32_C6_LIBRARY_4_ESP32_C6_LIBRARY_4_ES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
EPD_C1, EPD_C2: 1uF/50V; ESP32_C6_LIBRARY_1_ESP32_WROVER_EAGLE-LTSPICE_C0402
EPD_C5: 0.1uF/50V; GRM011R60J152KE01L_2_CAPC0201X13N
EPD_C6, EPD_C7, EPD_C8, EPD_C9, EPD_C10, EPD_C11, EPD_C12: 1uF/50V; NORDIC_NRF_3_RESC0402_L
IC2: DRV2605YZFR; DRV2605YZFR_BGA9C50P3X3_144X144X62
J1: 503480-2400; 503480-2400_5034802400
J4: KH-TYPE-C-16P; KH-TYPE-C-16P_KINGHELM_KH-TYPE-C-16P
L5: 68uH; ESP32_C6_LIBRARY_2_IND_4828-WE-TPC_WRE
Q3: SI1308EDL-T1-GE3; ESP32_C6_LIBRARY_6_SOT65P210X110-3N
R1_EP_DR: 0.47; CPF0201D7K68C1_0201
R1_USB, R2_USB: 5K1; CPF0201D7K68C1_0201
R2_EP_DR: 10K; CPF0201D7K68C1_0201
R5, R7, R8: 10k; CPF0201D7K68C1_0201
R_PWR_EPD: 10K; CPF0201D7K68C1_0201
R_TYPE_SEL: 2.2; CPF0201D7K68C1_0201
SJ1: ESP32_C6_LIBRARY_7_JUMPER_SJ
SW_DN: 2025-10-22_07-23-44_LIBRARY_EVP-AKE31ASW_EVP-AKE3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; 2025-10-22_07-23-44_LIBRARY_SW_EVP-AKE31A_PAN
SW_ENT: 2025-10-22_07-23-44_LIBRARY_EVP-AKE31ASW_EVP-AKE3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; 2025-10-22_07-23-44_LIBRARY_SW_EVP-AKE31A_PAN
SW_UP: 2025-10-22_07-23-44_LIBRARY_EVP-AKE31ASW_EVP-AKE3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; 2025-10-22_07-23-44_LIBRARY_SW_EVP-AKE31A_PAN
TP_BAT_GND: HECTOR_WATCH_1_TPTP20R; HECTOR_WATCH_1_TP20R
TP_ON: HECTOR_WATCH_1_TPTP20R; HECTOR_WATCH_1_TP20R
TP_OP: HECTOR_WATCH_1_TPTP20R; HECTOR_WATCH_1_TP20R
TP_VBAT: HECTOR_WATCH_1_TPTP20R; HECTOR_WATCH_1_TP20R
U3: MAX17048G+T10; ESP32_C6_LIBRARY_SON50P200X200X80-9N

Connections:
3V3: C34.2, DMG2305UX-7.2 (S), IC2.C2 (VDD), R5.2, R7.2, R8.2, R_PWR_EPD.2; also elsewhere on the board
ALERT: U3.5 (!ALERT); also elsewhere on the board
D+: D3.4 (I/O2_2); also elsewhere on the board
D-: D3.6 (I/O1_2); also elsewhere on the board
DN: D3.1 (I/O1_1), J4.A7 (DN1), J4.B7 (DN2)
DP: D3.3 (I/O2_1), J4.A6 (DP1), J4.B6 (DP2)
EPD_3V3: C1-EP-DR.1, DMG2305UX-7.3 (D), EPD_C5.2, J1.15, J1.16, L5.2
EPD_BUSY: J1.9; also elsewhere on the board
EPD_CS: J1.12; also elsewhere on the board
EPD_DC: J1.11; also elsewhere on the board
EPD_RST: J1.10; also elsewhere on the board
GDR: J1.2, Q3.1 (G), R2_EP_DR.2
HAPTIC_EN: IC2.A1 (EN); also elsewhere on the board
MOSI: J1.14; also elsewhere on the board
unnamed: C32.1, IC2.A2 (REG)
unnamed: J4.B5 (CC2), R2_USB.1
unnamed: J4.A5 (CC1), R1_USB.2
unnamed: C2-EP-DR.2, D5.2 (A), L5.1, Q3.3 (D)
unnamed: EPD_C2.2, J1.4
unnamed: EPD_C1.2, J1.5
unnamed: C2-EP-DR.1, D2.1 (K), D4.2 (A)
unnamed: EPD_C6.2, J1.18
unnamed: EPD_C7.2, J1.19
unnamed: EPD_C8.2, J1.20
unnamed: R1_EP_DR.1, R_TYPE_SEL.2, SJ1.2
unnamed: EPD_C10.2, J1.22
unnamed: EPD_C12.2, J1.24
OUT+: IC2.A3 (OUT+), TP_OP.TP
OUT-: IC2.C3 (OUT-), TP_ON.TP
P0.13: C30.2, R5.1, SW_UP.2; also elsewhere on the board
P0.14: C31.2, R8.1, SW_ENT.2; also elsewhere on the board
P1.01: DMG2305UX-7.1 (G), R_PWR_EPD.1; also elsewhere on the board
P1.02: C29.2, R7.1, SW_DN.2; also elsewhere on the board
PREVGH: D5.1 (K), EPD_C9.2, J1.21
PREVGL: D2.2 (A), EPD_C11.2, J1.23
RESE: J1.3, Q3.2 (S), R1_EP_DR.2
SCK: J1.13; also elsewhere on the board
SCL: IC2.C1 (SCL), U3.7 (SCL); also elsewhere on the board
SDA: IC2.B2 (SDA), U3.8 (SDA); also elsewhere on the board
VBAT: C27.1, TP_VBAT.TP, U3.2 (CELL), U3.3 (VDD); also elsewhere on the board
VBUS: C42.1, C43.1, D3.5 (VBUS), J4.A4_B9 (VBUS), J4.A9_B4 (VBUS); also elsewhere on the board

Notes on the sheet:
Buttons
Haptic Driver
Fuel Gauge
drawn by: Sadeghi Far Ariana
E-Paper & Peripherals
USB C Connector & ESD Protection
E-Paper Display Connector
E-Paper Drive Circuit

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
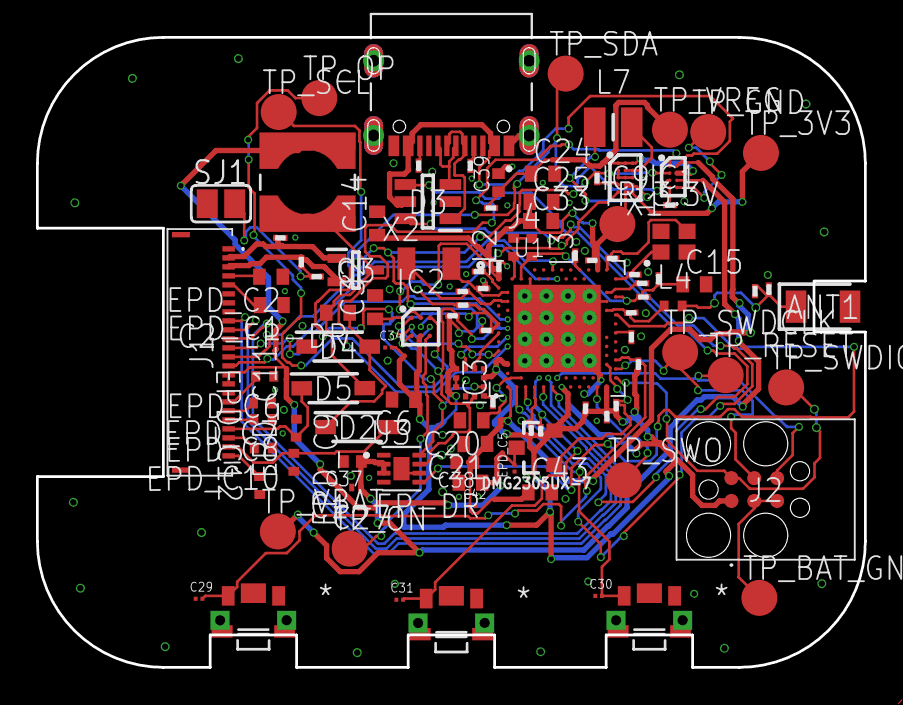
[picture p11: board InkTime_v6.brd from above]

Board: 2 copper layers, 46.0 x 35.0 mm, 105 parts (0 on the bottom side), 70 nets.

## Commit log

2026-04-10 Enhance README with project details and diagrams
    Updated README.md to include additional details about the InkTime smartwatch project, including system block diagram, BOM, hardware functionality, pin allocation, and mechanical integration.
2026-04-15 Add files via upload
    Added Mechanical folder and Schematic.pdf in Hardware folder
2026-04-20 Add files via upload
    Fixed PCB
    [InkTime_v6.brd]
2026-04-20 Enhance README with power budget and design details
    Updated README.md to include additional sections and detailed power consumption estimates for the InkTime smartwatch project.

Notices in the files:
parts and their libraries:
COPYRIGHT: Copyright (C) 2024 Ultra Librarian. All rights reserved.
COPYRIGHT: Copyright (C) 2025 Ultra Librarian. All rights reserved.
